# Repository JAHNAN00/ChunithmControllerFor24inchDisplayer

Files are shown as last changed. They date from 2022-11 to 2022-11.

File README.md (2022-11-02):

# 适配24寸显示器的中二控制器
全部是直插式元件，买来焊上就行

## 材料清单
* Arduino Pro Micro \* 1
* Mpr121模块 \* 3
* XH2.54端子若干
* 直插式三极管 \* 6
* 红外led发射器和接收器若干
* 电阻若干

## 做法
照着pcb的图焊上就行





然后用Arduino IDE上传一下代码，在游戏体里修改一下按键

如果觉得触摸板背后有排针，不平滑，可以找淘宝加工一块文件里的亚克力，不过有点小贵。

## 游戏按键设置
```
[slider]
cell32=0x41
cell31=0x42
cell30=0x43
cell29=0x44
cell28=0x45
cell27=0x46
cell26=0x47
cell25=0x48
cell24=0x49
cell23=0x4A
cell22=0x4B
cell21=0x4C
cell20=0x4D
cell19=0x4E
cell18=0x4F
cell17=0x50
cell16=0x51
cell15=0x52
cell14=0x53
cell13=0x54
cell12=0x55
cell11=0x56
cell10=0x57
cell9=0x58
cell8=0x59
cell7=0x5A;a-z
cell6=0x34
cell5=0x35
cell4=0x36
cell3=0x37
cell2=0x38
cell1=0x39

[ir]
ir6=0xdd
ir5=0xdb
ir1=0xbe
ir2=0xbf
ir3=0xba
ir4=0xde
```

## 实物

d64ac3bacf77936e5221e14f8255fbc

游玩视频：
https://www.bilibili.com/video/BV1fP4y1f7VN/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

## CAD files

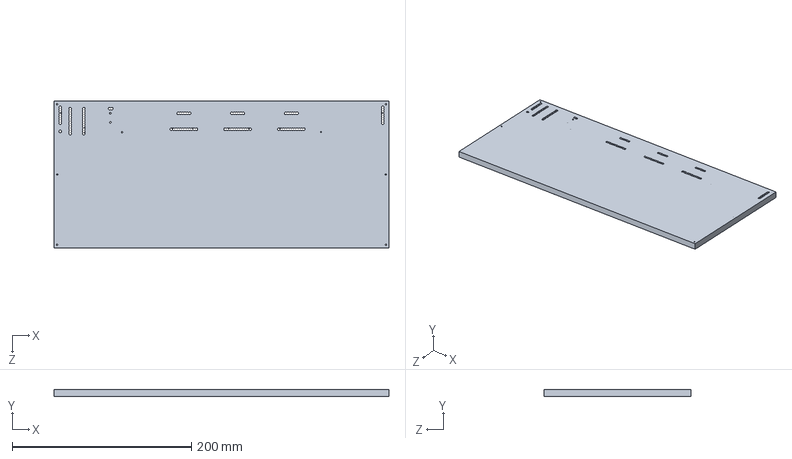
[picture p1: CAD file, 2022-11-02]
others/底盘.SLDPRT
374.0 x 8.00 x 164.0 mm

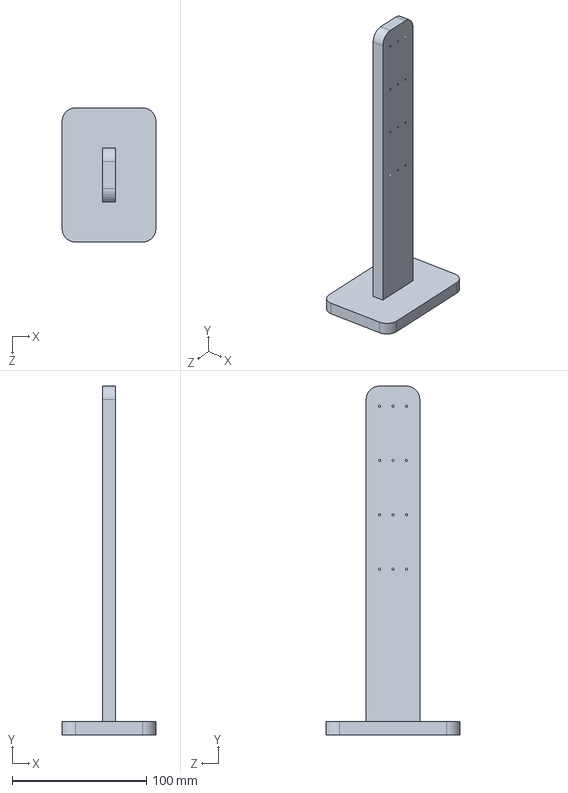
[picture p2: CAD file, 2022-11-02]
others/发射和接收端底座.SLDPRT
70.0 x 260.0 x 100.0 mm

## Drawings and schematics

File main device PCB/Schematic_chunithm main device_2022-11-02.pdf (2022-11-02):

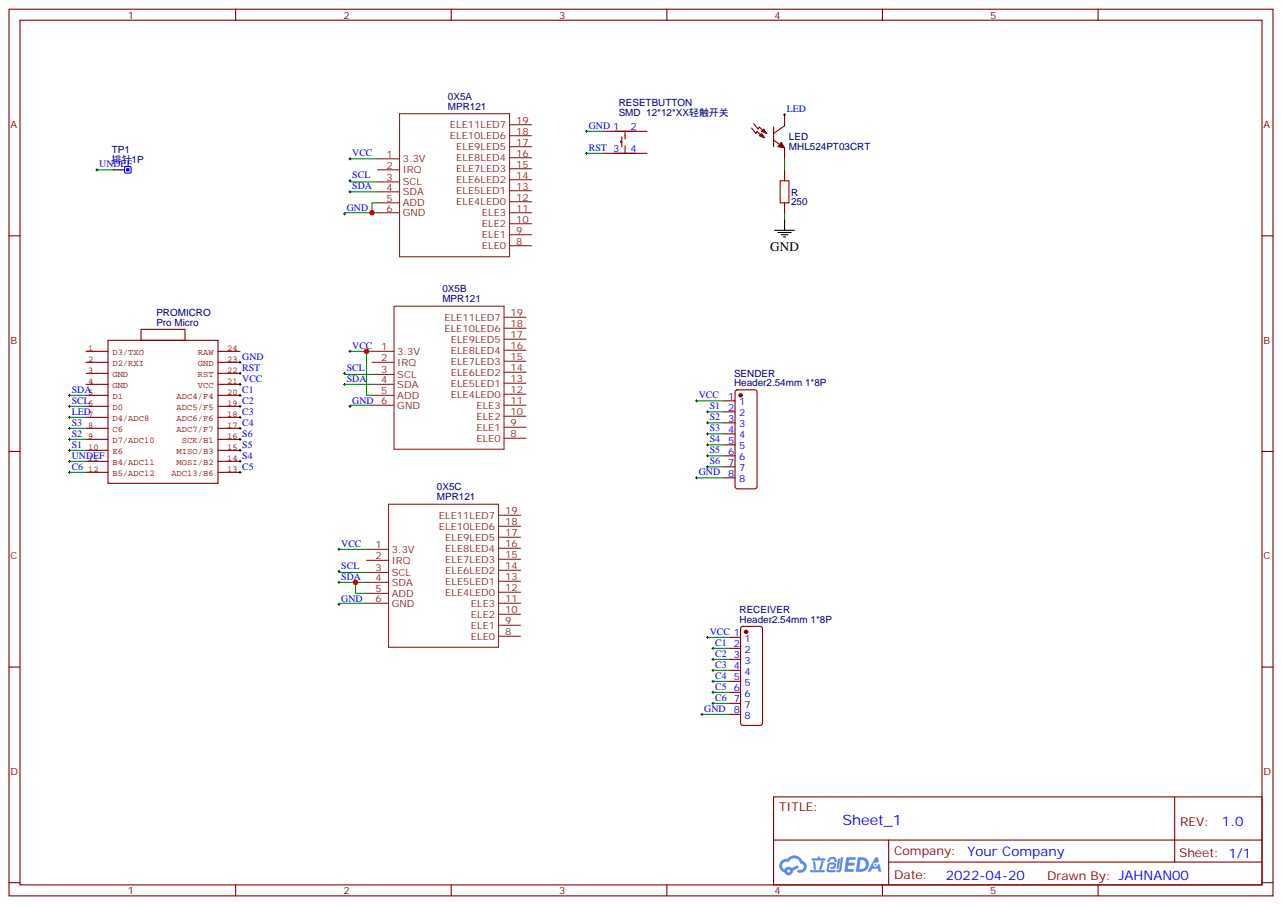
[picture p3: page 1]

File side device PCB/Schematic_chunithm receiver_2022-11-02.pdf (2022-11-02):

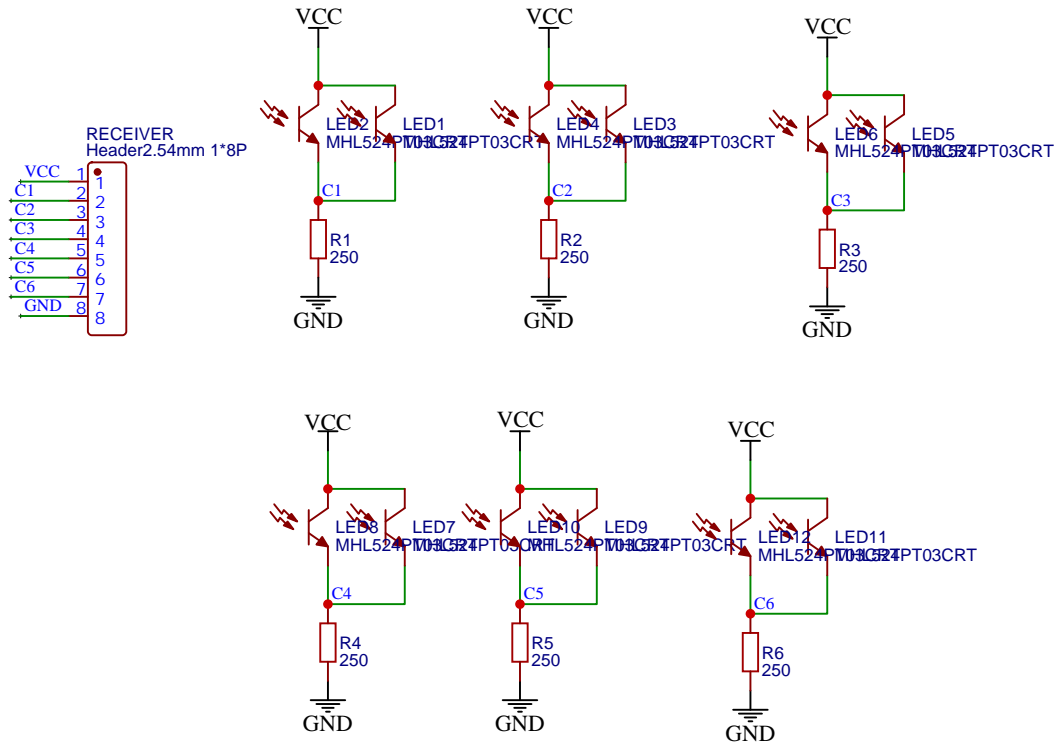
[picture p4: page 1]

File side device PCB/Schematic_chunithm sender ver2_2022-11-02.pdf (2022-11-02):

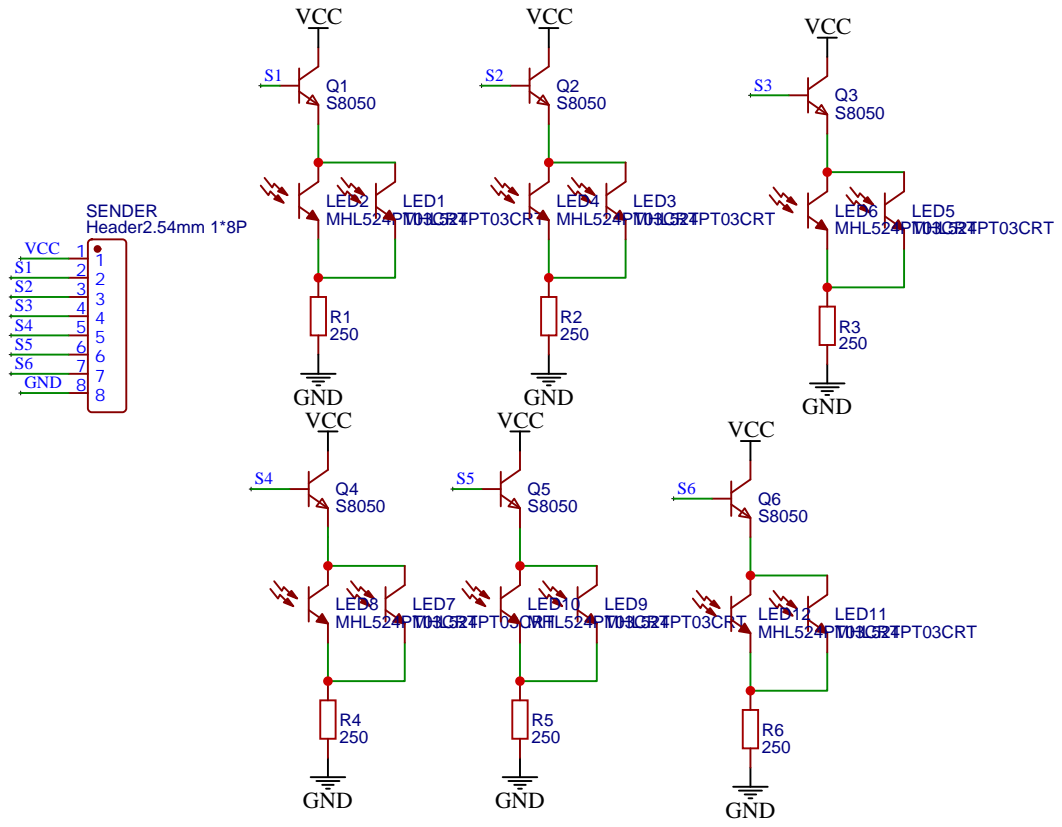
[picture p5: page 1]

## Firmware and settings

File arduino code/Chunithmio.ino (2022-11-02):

#include <Wire.h>
#include "MPR121.h"
#include <HID-Project.h>
#include "air.h"

#ifndef _BV
#define _BV(bit) (point << (bit)) 
#endif

Adafruit_MPR121 capl = Adafruit_MPR121();
Adafruit_MPR121 capm = Adafruit_MPR121();
Adafruit_MPR121 capr = Adafruit_MPR121();

uint32_t lasttouched = 0;
uint32_t currtouched = 0;

uint32_t point = 1;

uint8_t air=0;


void setup() {

  //while (!Serial) { // needed to keep leonardo/micro from starting too fast!
  //  delay(10);
  //}
  setlight(1,1);
  setlight(2,1);
  setlight(3,1);
  setlight(4,1);
  setlight(5,1);
  setlight(6,1);
  
  capl.begin(0x5a);
  capm.begin(0x5b);
  capr.begin(0x5c);

  NKROKeyboard.releaseAll();
  
  //Serial.println("MPR121 found!");
}

void loop(){
  currtouched=capl.touched();
  currtouched|=(uint32_t(capm.touched()))<<12;
  currtouched|=(uint32_t(capr.touched()))<<24;
  
  //Serial.println(currtouched,BIN);
  uint8_t i;
  for(i=0;i<32;i++){
    if((currtouched&point<<i) && !(lasttouched&point<<i)){
      NKROKeyboard.add(i<26?0x41+i:0x34+i-26);
      //Serial.println(i<26?0x41+i:0x34+i-26);
    }
    if (!(currtouched &point<<i) && (lasttouched & point<<i) ) {
      NKROKeyboard.remove(i<26?0x41+i:0x34+i-26);
    }
  }
 
  
  for(i=1;i<=6;i++){
    setairkey(i,checkair(i,air));
    setlight(i+1,1);
    setlight(i,0);
    delay(1);
  }//

  NKROKeyboard.send();
  lasttouched = currtouched;
  currtouched = 0;
}

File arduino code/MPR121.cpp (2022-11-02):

/*!
 * @file Adafruit_MPR121.cpp
 *
 *  @mainpage Adafruit MPR121 arduino driver
 *
 *  @section intro_sec Introduction
 *
 *  This is a library for the MPR121 I2C 12-chan Capacitive Sensor
 *
 *  Designed specifically to work with the MPR121 sensor from Adafruit
 *  ----> https://www.adafruit.com/products/1982
 *
 *  These sensors use I2C to communicate, 2+ pins are required to
 *  interface
 *
 *  Adafruit invests time and resources providing this open source code,
 *  please support Adafruit and open-source hardware by purchasing
 *  products from Adafruit!
 *
 *  @section author Author
 *
 *  Written by Limor Fried/Ladyada for Adafruit Industries.
 *
 *  @section license License
 *
 *  BSD license, all text here must be included in any redistribution.
 */

#include "MPR121.h"

// uncomment to use autoconfig !
//#define AUTOCONFIG // use autoconfig (Yes it works pretty well!)

/*!
 *  @brief      Default constructor
 */
Adafruit_MPR121::Adafruit_MPR121() {}

/*!
 *  @brief    Begin an MPR121 object on a given I2C bus. This function resets
 *            the device and writes the default settings.
 *  @param    i2caddr
 *            the i2c address the device can be found on. Defaults to 0x5A.
 *  @param    *theWire
 *            Wire object
 *  @param    touchThreshold
 *            touch detection threshold value
 *  @param    releaseThreshold
 *            release detection threshold value
 *  @returns  true on success, false otherwise
 */
bool Adafruit_MPR121::begin(uint8_t i2caddr, TwoWire *theWire,
                            uint8_t touchThreshold, uint8_t releaseThreshold) {

  if (i2c_dev) {
    delete i2c_dev;
  }
  i2c_dev = new Adafruit_I2CDevice(i2caddr, theWire);

  if (!i2c_dev->begin()) {
    return false;
  }

  // soft reset
  writeRegister(MPR121_SOFTRESET, 0x63);
  delay(1);
  for (uint8_t i = 0; i < 0x7F; i++) {
    //  Serial.print("$"); Serial.print(i, HEX);
    //  Serial.print(": 0x"); Serial.println(readRegister8(i));
  }

  writeRegister(MPR121_ECR, 0x0);

  uint8_t c = readRegister8(MPR121_CONFIG2);

  if (c != 0x24)
    return false;

  setThresholds(touchThreshold, releaseThreshold);
  writeRegister(MPR121_MHDR, 0x01);
  writeRegister(MPR121_NHDR, 0x08);
  writeRegister(MPR121_NCLR, 0x01);
  writeRegister(MPR121_FDLR, 0x00);

  writeRegister(MPR121_MHDF, 0x01);
  writeRegister(MPR121_NHDF, 0x01);
  writeRegister(MPR121_NCLF, 0x10);
  writeRegister(MPR121_FDLF, 0x02);

  writeRegister(MPR121_NHDT, 0x00);
  writeRegister(MPR121_NCLT, 0x00);
  writeRegister(MPR121_FDLT, 0x00);

  writeRegister(MPR121_DEBOUNCE, 0);
  writeRegister(MPR121_CONFIG1, 0x10); // default, 16uA charge current
  writeRegister(MPR121_CONFIG2, 0x20); // 0.5uS encoding, 1ms period

#ifdef AUTOCONFIG
  writeRegister(MPR121_AUTOCONFIG0, 0x0B);

  // correct values for Vdd = 3.3V
  writeRegister(MPR121_UPLIMIT, 200);     // ((Vdd - 0.7)/Vdd) * 256
  writeRegister(MPR121_TARGETLIMIT, 180); // UPLIMIT * 0.9
  writeRegister(MPR121_LOWLIMIT, 130);    // UPLIMIT * 0.65
#endif

  // enable X electrodes and start MPR121
  byte ECR_SETTING =
      B10000000 + 12; // 5 bits for baseline tracking & proximity disabled + X
                      // amount of electrodes running (12)
  writeRegister(MPR121_ECR, ECR_SETTING); // start with above ECR setting

  return true;
}

/*!
 *  @brief      DEPRECATED. Use Adafruit_MPR121::setThresholds(uint8_t touch,
 *              uint8_t release) instead.
 *  @param      touch
 *              see Adafruit_MPR121::setThresholds(uint8_t touch, uint8_t
 * *release)
 *  @param      release
 *              see Adafruit_MPR121::setThresholds(uint8_t touch, *uint8_t
 * release)
 */
void Adafruit_MPR121::setThreshholds(uint8_t touch, uint8_t release) {
  setThresholds(touch, release);
}

/*!
 *  @brief      Set the touch and release thresholds for all 13 channels on the
 *              device to the passed values. The threshold is defined as a
 *              deviation value from the baseline value, so it remains constant
 * even baseline value changes. Typically the touch threshold is a little bigger
 * than the release threshold to touch debounce and hysteresis. For typical
 * touch application, the value can be in range 0x05~0x30 for example. The
 * setting of the threshold is depended on the actual application. For the
 * operation details and how to set the threshold refer to application note
 * AN3892 and MPR121 design guidelines.
 *  @param      touch
 *              the touch threshold value from 0 to 255.
 *  @param      release
 *              the release threshold from 0 to 255.
 */
void Adafruit_MPR121::setThresholds(uint8_t touch, uint8_t release) {
  // set all thresholds (the same)
  for (uint8_t i = 0; i < 12; i++) {
    writeRegister(MPR121_TOUCHTH_0 + 2 * i, touch);
    writeRegister(MPR121_RELEASETH_0 + 2 * i, release);
  }
}

/*!
 *  @brief      Read the filtered data from channel t. The ADC raw data outputs
 *              run through 3 levels of digital filtering to filter out the high
 * frequency and low frequency noise encountered. For detailed information on
 * this filtering see page 6 of the device datasheet.
 *  @param      t
 *              the channel to read
 *  @returns    the filtered reading as a 10 bit unsigned value
 */
uint16_t Adafruit_MPR121::filteredData(uint8_t t) {
  if (t > 12)
    return 0;
  return readRegister16(MPR121_FILTDATA_0L + t * 2);
}

/*!
 *  @brief      Read the baseline value for the channel. The 3rd level filtered
 *              result is internally 10bit but only high 8 bits are readable
 * from registers 0x1E~0x2A as the baseline value output for each channel.
 *  @param      t
 *              the channel to read.
 *  @returns    the baseline data that was read
 */
uint16_t Adafruit_MPR121::baselineData(uint8_t t) {
  if (t > 12)
    return 0;
  uint16_t bl = readRegister8(MPR121_BASELINE_0 + t);
  return (bl << 2);
}

/**
 *  @brief      Read the touch status of all 13 channels as bit values in a 12
 * bit integer.
 *  @returns    a 12 bit integer with each bit corresponding to the touch status
 *              of a sensor. For example, if bit 0 is set then channel 0 of the
 * device is currently deemed to be touched.
 */
uint16_t Adafruit_MPR121::touched(void) {
  uint16_t t = readRegister16(MPR121_TOUCHSTATUS_L);
  return t & 0x0FFF;
}

/*!
 *  @brief      Read the contents of an 8 bit device register.
 *  @param      reg the register address to read from
 *  @returns    the 8 bit value that was read.
 */
uint8_t Adafruit_MPR121::readRegister8(uint8_t reg) {
  Adafruit_BusIO_Register thereg = Adafruit_BusIO_Register(i2c_dev, reg, 1);

  return (thereg.read());
}
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

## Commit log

2022-11-02 PCB Gerber and schematic
2022-11-02 触摸板的pcb文件
2022-11-02 红外发射接收器的PCB文件
2022-11-02 主控的arduino程序
